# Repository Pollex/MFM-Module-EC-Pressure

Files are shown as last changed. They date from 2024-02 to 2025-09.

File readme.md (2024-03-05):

## TODOs

### Open Q's
- [ ] Calibration must happens when probe is switched. When and how to do this?
- [ ] Is it worth disabling the EZO circuit LED?
  - Perhaps sending the command takes more power than the LED being on

### Atlas Scientific EZO Circuit
- [ ] Send probe K value from EEPROM in perform_measurement
- [ ] Send calibration string from EEPROM in perform_measurement
- [ ] Send water temperature from EEPROM in perform_measurement

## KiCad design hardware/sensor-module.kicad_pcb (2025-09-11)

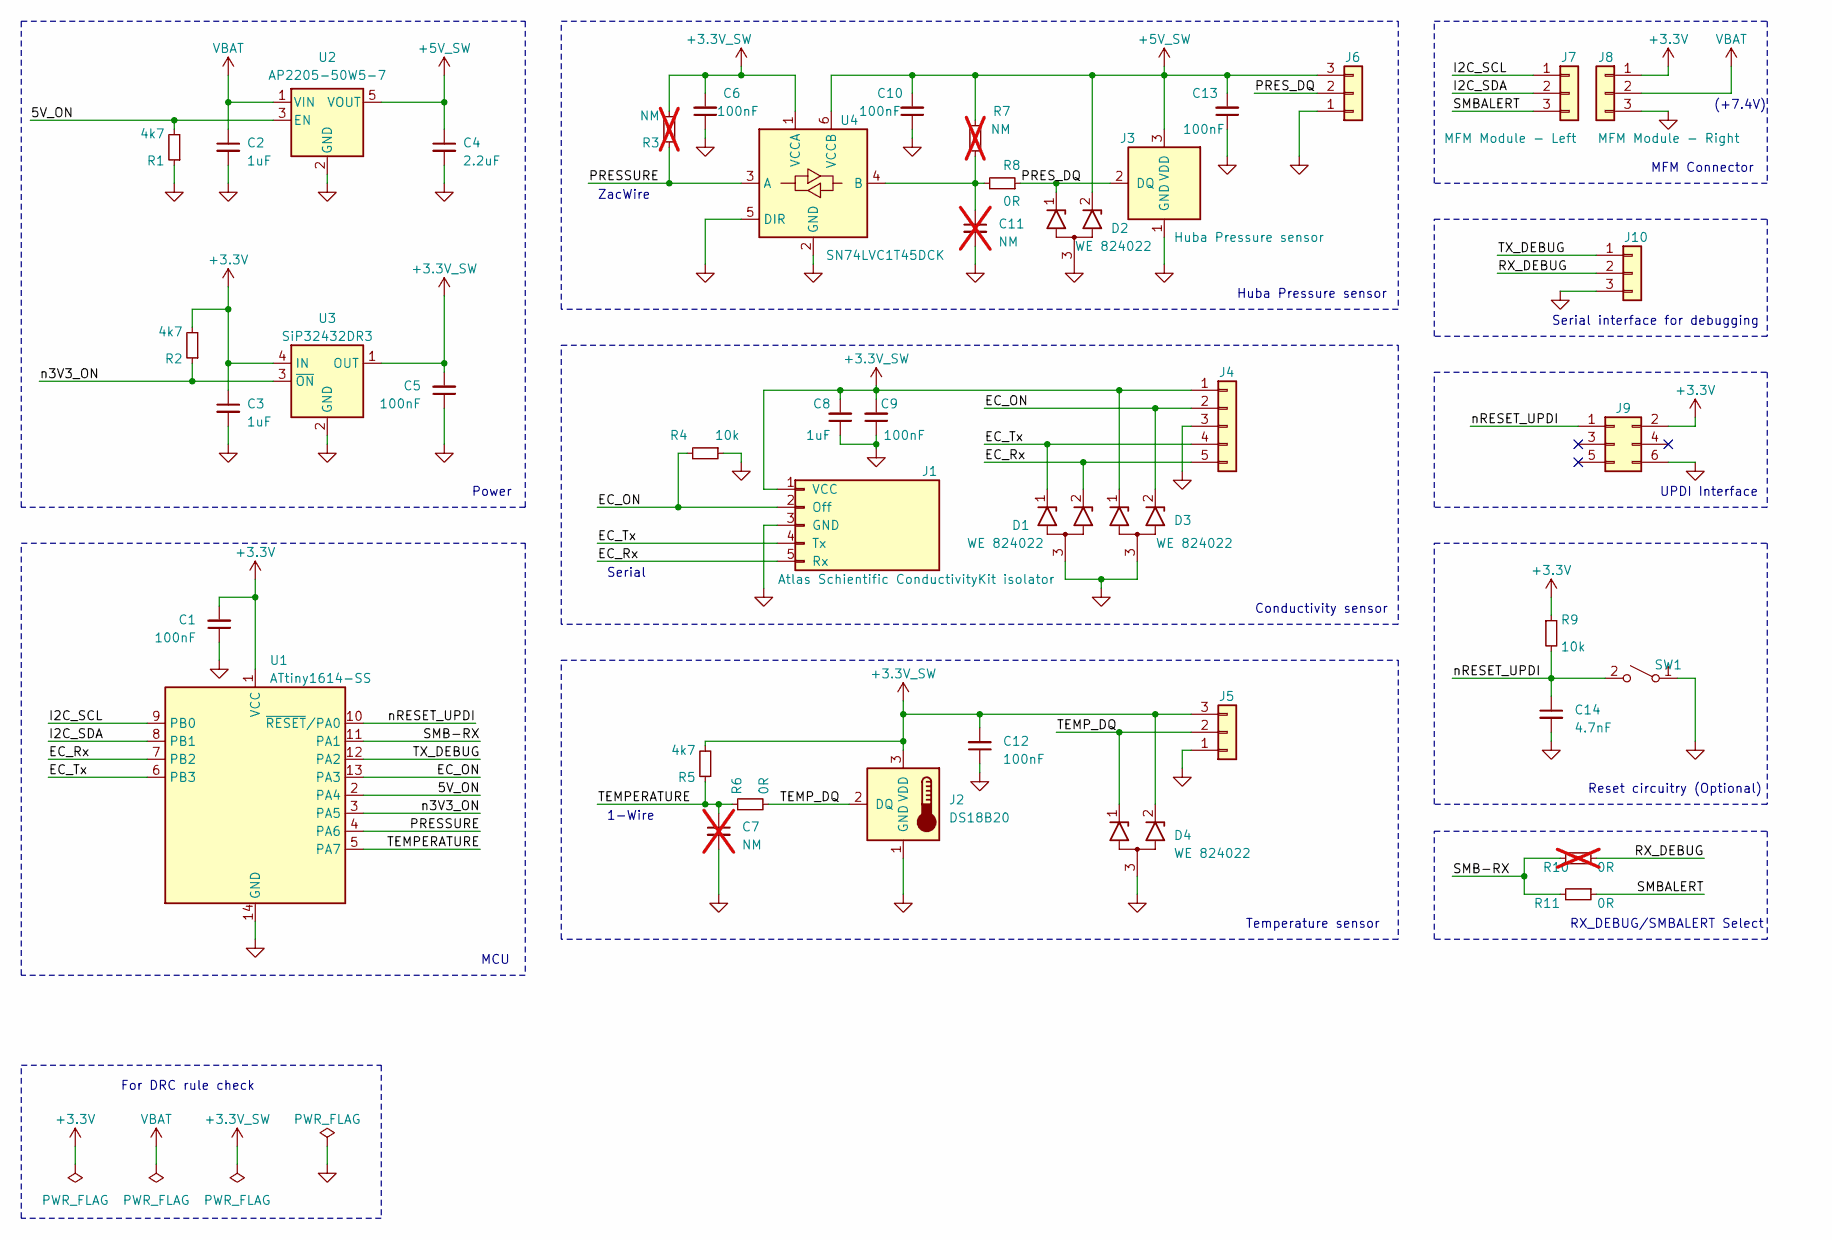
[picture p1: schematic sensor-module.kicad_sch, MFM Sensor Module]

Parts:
C1, C5, C6, C9, C10, C12, C13: 100nF; C_0603_1608Metric
C2, C3, C8: 1uF; C_0805_2012Metric
C4: 2.2uF; C_0805_2012Metric
C7, C11: NM; C_0603_1608Metric; not fitted
C14: 4.7nF; C_0603_1608Metric
D1, D2, D3, D4: WE 824022; SOT-23-3L
J1: Atlas Schientific ConductivityKit isolator; TerminalBlock_Phoenix_MPT-0,5-5-2.54_1x05_P2.54mm_Horizontal
J2: DS18B20; TerminalBlock_Phoenix_MPT-0,5-3-2.54_1x03_P2.54mm_Horizontal
J3: Huba Pressure sensor; TerminalBlock_Phoenix_MPT-0,5-3-2.54_1x03_P2.54mm_Horizontal
J4: Conductivity; PinHeader_1x05_P2.54mm_Vertical
J5: Temperature; PinHeader_1x03_P2.54mm_Vertical
J6: Huba Pressure; PinHeader_1x03_P2.54mm_Vertical
J7: MFM Module - Left; PinHeader_1x03_P2.54mm_Vertical
J8: MFM Module - Right; PinHeader_1x03_P2.54mm_Vertical
J9: UPDI Interface; PinHeader_2x03_P2.54mm_Vertical
J10: Debug UART; PinHeader_1x03_P2.54mm_Vertical
R1, R2, R5: 4k7; C_0603_1608Metric
R3, R7: NM; C_0603_1608Metric; not fitted
R4, R9: 10k; C_0603_1608Metric
R6, R8, R11: 0R; C_0603_1608Metric
R10: 0R; C_0603_1608Metric; not fitted
SW1: PTS636 SM43 SMTR LFS; SW_Tactile_SPST_NO_Straight_CK_PTS636Sx25SMTRLFS
U1: ATtiny1614-SS; SOIC-14_3.9x8.7mm_P1.27mm
U2: AP2205-50W5-7; SOT-23-5
U3: SiP32432DR3; SOT-363_SC-70-6
U4: SN74LVC1T45DCK; SOT-363_SC-70-6

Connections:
+3.3V: C1.2, C3.1, J8.1, J9.2, R2.2, R9.1, U1.1 (VCC), U3.4 (IN)
+3.3V_SW: C5.2, C6.2, C8.2, C9.2, C12.2, D3.1 (K1), D4.2 (K2), J1.1 (VCC), J2.3 (VDD), J4.1, J5.3, R3.2, R5.2, U3.1 (OUT), U4.1 (VCCA)
+5V_SW: C4.1, C10.2, C13.2, D2.2 (K2), J3.3 (VDD), J6.3, R7.2, U2.5 (VOUT), U4.6 (VCCB)
/5V_ON: R1.2, U1.2 (PA4), U2.3 (EN)
/EC_ON: D3.2 (K2), J1.2 (Off), J4.2, R4.2, U1.13 (PA3)
/EC_Rx: D1.2 (K2), J1.5 (Rx), J4.5, U1.7 (PB2)
/EC_Tx: D1.1 (K1), J1.4 (Tx), J4.4, U1.6 (PB3)
/I2C_SCL: J7.1, U1.9 (PB0)
/I2C_SDA: J7.2, U1.8 (PB1)
/PRESSURE: R3.1, U1.4 (PA6), U4.3 (A)
/PRES_DQ: D2.1 (K1), J3.2 (DQ), J6.2, R8.1
/RX_DEBUG: J10.2, R10.1
/SMB-RX: R10.2, R11.2, U1.11 (PA1)
/SMBALERT: J7.3, R11.1
/TEMPERATURE: C7.1, R5.1, R6.1, U1.5 (PA7)
/TEMP_DQ: D4.1 (K1), J2.2 (DQ), J5.2, R6.2
/TX_DEBUG: J10.1, U1.12 (PA2)
/n3V3_ON: R2.1, U1.3 (PA5), U3.3 (~ON)
/nRESET_UPDI: C14.1, J9.1, R9.2, SW1.2 (B), U1.10 (~RESET/PA0)
GND: C1.1, C2.2, C3.2, C4.2, C5.1, C6.1, C7.2, C8.1, C9.1, C10.1, C11.2, C12.1, C13.1, C14.2, D1.3 (A), D2.3 (A), D3.3 (A), D4.3 (A), J1.3 (GND), J2.1 (GND), J3.1 (GND), J4.3, J5.1, J6.1, J8.3, J9.6, J10.3, R1.1, R4.1, SW1.1 (A), U1.14 (GND), U2.2 (GND), U3.2 (GND), U3.5 (GND), U4.2 (GND), U4.5 (DIR)
unnamed: C11.1, R7.1, R8.2, U4.4 (B)
VBAT: C2.1, J8.2, U2.1 (VIN)

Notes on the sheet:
Serial
Conductivity sensor
1-Wire
Huba Pressure sensor
Serial interface for debugging
Temperature sensor
ZacWire
RX_DEBUG/SMBALERT Select
(+7.4V)
For DRC rule check
MCU
MFM Connector
Power
UPDI Interface
Reset circuitry (Optional)

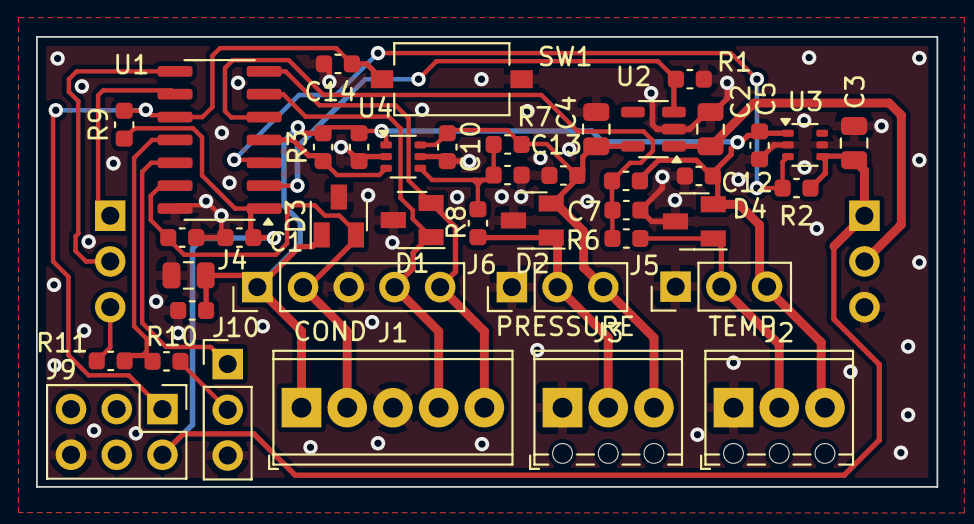
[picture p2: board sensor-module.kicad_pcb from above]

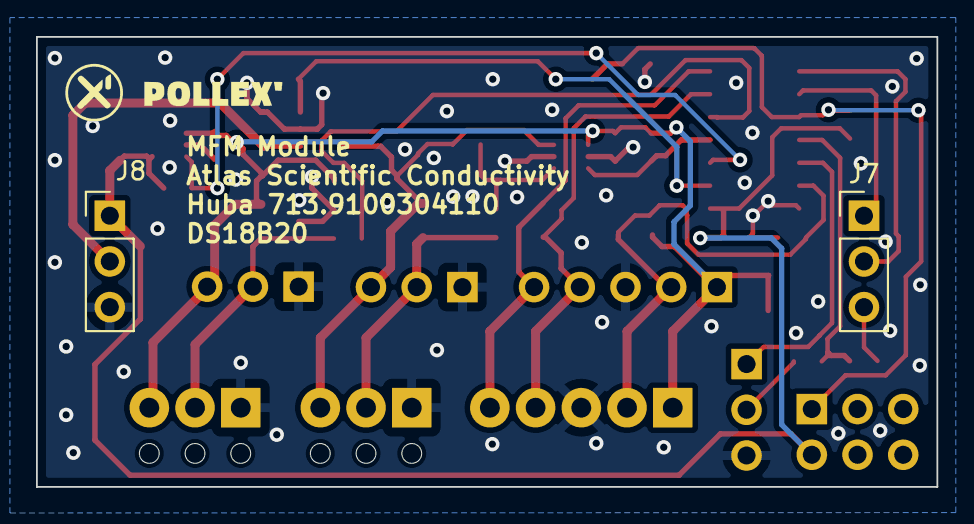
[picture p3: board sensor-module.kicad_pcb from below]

Board: 2 copper layers, 50.0 x 25.0 mm, 44 parts (2 on the bottom side), 22 nets.

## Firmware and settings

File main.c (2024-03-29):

// #include <stdio.h>
// #include <avr/iotn1614.h>
/// @mainpage MFM Sensor Module
/// @brief Main file for the MFM Sensor Module
/// @details This application will initialize the MFM Sensor board and perform
/// measurements from the following sensors:
/// - Huba713 sensor
/// - DS18B20 temperature sensor
/// - Atlas Scientific EZO EC sensor
/// Measurements are started by the I2C master by sending a command 0x10 to the
/// MFM Sensor Module (I2C address 0x36) The measurements will be stored in a
/// data packet and can be requested by the I2C master by sending a command 0x11
/// The data packet will be sent back to the I2C master and is defined as below,
/// - Number of bytes in the data packet (uint8_t)
/// - Huba713 pressure (uint16_t )
/// - Huba713 temperature (float in degrees Celsius)
/// - DS18B20 temperature (float in degrees Celsius)
/// - Atlas Scientific EZO EC conductivity (uint8_t[4]; string holding uS/cm)
/// The data will be in little-endian format
///
/// An example of the data packet:
/// > 0E C1 0B E0 7A A4 41 00 00 AD 41 30 2E 30 30
///
/// - Number of data bytes: 14
/// - Pressure: 3009
/// - Temperature: 20.5599975585
/// - ds18b20_temperature: 21.625
/// - conductivity: 0.00
/// When the MFM Sensor Module is not performing measurements, it will be in
/// sleep mode to save power

#include "board/mfm_sensor_module.h"

#include <avr/io.h>
#include <avr/wdt.h>

#include <avr/interrupt.h>
#include <avr/sleep.h>
#include <stdint.h>
#include <util/atomic.h>

#include "drivers/zacwire.h"
#include "mcu/twi.h"
#include "mcu/util.h"
#include "os/os.h"
#include "perif/atlas_ezo_ec.h"
#include "perif/ds18b20.h"
#include "perif/huba713.h"
#include <string.h>

// Power control
#define PWR_DISABLE 0x00
#define PWR_ENABLE 0x01

// forward declarations
static void pwr_5vEnable(uint8_t enable);
static void pwr_3v3Enable(uint8_t enable);
static void pwr_init(void);

void perform_measurements(void);

#define FLAG_CALIBRATED 0x01
#define FLAG_HUBA_ERR 0x02
#define HUBA_MEDIAN_COUNT 11

// Forward declaration of variables
/// @brief I2C Data packet
struct packet_t {
    uint16_t huba_pressure;
    float huba_temperature;
    float ds18b20_temperature;
    uint8_t atlas_conductivity[8];
    uint8_t flags;
} packet;

// "tasks" that will be performed on wakeup (interrupt)
volatile uint8_t doCalibration = 0;
volatile uint8_t doMeasurement = 0;

/// @brief DS18B20 struct to hold resolution, defined here so we can set it once
/// in main
ds18b20_t d;

/// @brief Initialize the power control
/// @details 5V and 3V3 will be disabled after initialization
void pwr_init(void) {
    ENABLE_5V_PORT.DIRSET = ENABLE_5V_PIN;   // 5V_on as output
    ENABLE_3V3_PORT.DIRSET = ENABLE_3V3_PIN; // 3V3_on as output

    pwr_3v3Enable(PWR_DISABLE);
    pwr_5vEnable(PWR_DISABLE);
}

/// @brief Enable/disable 5V
/// @param enable PWR_DISABLE (0x00) to disable, PWR_ENABLE (0x01) to enable
void pwr_5vEnable(uint8_t enable) {
    if (enable > 0) {
        ENABLE_5V_PORT.OUTSET = ENABLE_5V_PIN; // Switch 5V_on to on
    } else {
        ENABLE_5V_PORT.OUTCLR = ENABLE_5V_PIN; // Switch 5V_on to off
    }
}

/// @brief Enable/disable 3V3
/// @param enable PWR_DISABLE (0x00) to disable, PWR_ENABLE (0x01) to enable
void pwr_3v3Enable(uint8_t enable) {
    if (enable > 0) {
        ENABLE_3V3_PORT.OUTCLR = ENABLE_3V3_PIN; // Switch 3V3_on to on
    } else {
        ENABLE_3V3_PORT.OUTSET = ENABLE_3V3_PIN; // Switch 3V3_on to off
    }
}

/* Function to sort an array using insertion sort*/
void insertion_sort_u16(uint16_t arr[], int n) {
    int i, key, j;
    for (i = 1; i < n; i++) {
        key = arr[i];
        j = i - 1;

        /* Move elements of arr[0..i-1], that are
        greater than key, to one position ahead
        of their current position */
        while (j >= 1 && arr[j] > key) {
            arr[j + 1] = arr[j];
            j = j - 1;
        }
        arr[j + 1] = key;
    }
}

/* Function to sort an array using insertion sort*/
void insertion_sort_f(float arr[], int n) {
    int i, key, j;
    for (i = 1; i < n; i++) {
        key = arr[i];
        j = i - 1;

        /* Move elements of arr[0..i-1], that are
        greater than key, to one position ahead
        of their current position */
        while (j >= 1 && arr[j] > key) {
            arr[j + 1] = arr[j];
            j = j - 1;
        }
        arr[j + 1] = key;
    }
}

/// @brief Perform measurements from different sensors and store them in global
/// variables
/// @details This function is called from the twi_perform_task, which is called
/// from the I2C ISR it will enable 5V and 3V3, initialize sensors, perform the
/// measurements and disable 5V and 3V3
void perform_measurements() {
    // Conductivity data (string holding uS/cm)
    static uint8_t conductivity[8] = {0};
    static float ds18b20_temperature;
    static uint16_t huba_pressure = 0;
    static float huba_temperature = 0.0;

    uint16_t median_pressure[HUBA_MEDIAN_COUNT] = {0};
    float median_temperature[HUBA_MEDIAN_COUNT] = {0};

    // Enable 5V and 3V3
    pwr_5vEnable(PWR_ENABLE);
    pwr_3v3Enable(PWR_ENABLE);
    delay_ms(10);

    // Measure huba sensor using median filter
    int errs = 0;
    int index = 0;
    for (uint8_t tries = 0; tries < HUBA_MEDIAN_COUNT; tries++) {
        // read value from Huba sensor (zacwire)
        int err = huba713_read(&huba_pressure, &huba_temperature);
        if (err == 0) {
            median_pressure[index] = huba_pressure;
            median_temperature[index++] = huba_temperature;
        } else {
            errs++;
        }
    }

    // The HUBA sensor is the only sensor in need of 5V, so disable it after
    // reading
    pwr_5vEnable(PWR_DISABLE);

    // Prepare HUBA Sensor values
    if (errs > 0) {
        packet.flags |= FLAG_HUBA_ERR;
    }
    // Make sure there is atleast one valid measurements to perform median
    if (index > 0) {
        insertion_sort_u16(median_pressure, index);
        insertion_sort_f(median_temperature, index);
        huba_pressure = median_pressure[index / 2];
        huba_temperature = median_temperature[index / 2];
    } else {
        // Otherwise error
        huba_pressure = 0;
        huba_temperature = 200.0f;
    }
    delay_us(1000);

    // read value from DS18B20 sensor (one-wire)
    ds18b20_read(&d, 0);
    ds18b20_temperature = ds18b20_read(&d, 0);

    // Turn the Atlas Scientific EZO EC sensor on by setting the enable pin
    atlas_ezo_ec_enable();

    // We only want to read the value once, so disable continuous reading
    atlas_ezo_ec_disableContinuousReading();

    // Set temperature compensation
    if (ds18b20_temperature > -50 && ds18b20_temperature < 50) {
        atlas_ezo_ec_setTemperature((uint8_t)ds18b20_temperature);
    } else {
        atlas_ezo_ec_setTemperature(10);
    }

    if (doCalibration) {
        atlas_ezo_ec_calibrate();
        packet.flags |= FLAG_CALIBRATED;
        doCalibration = 0;
    }

    // read value from Atlas Scientific EZO EC sensor (UART)
    atlas_ezo_ec_requestValue(conductivity);

    // Small delay before turning off the sensor
    delay_us(200);
    // Turn the Atlas Scientific EZO EC sensor off by clearing the enable pin
    atlas_ezo_ec_disable();

    // Small delay to give the CPU time to read the last data from the UART
    delay_us(500);

    // All done, so disable 3V3
    pwr_3v3Enable(PWR_DISABLE);

    // Store the data in data struct
    packet.huba_pressure = huba_pressure;
    packet.huba_temperature = huba_temperature;
    packet.ds18b20_temperature = ds18b20_temperature;
    for (int ii = 0; ii < 8; ii++) {
        packet.atlas_conductivity[ii] = conductivity[ii];
    }
}

/// @brief Handler for cmd 0x80 from I2C master
/// @details Triggers a calibration
/// @param buf Pointer to the buffer to store the data in
/// @param len Length of the buffer
void twi_cmd_80_handler(uint8_t *buf, uint8_t len) { doCalibration = 1; }

/// @brief Handler for cmd 0x11 from I2C master
/// @details Copies the sensor data from the data packet to the bus; kept short
/// as possible!
/// @param buf Pointer to the buffer to store the data in
/// @param len Length of the buffer
void twi_cmd_11_handler(uint8_t *buf, uint8_t len) {
    buf[0] = sizeof(struct packet_t);
    memcpy(&buf[1], &packet, buf[0]);
    memset(&packet, 0, sizeof(struct packet_t));
}

/// @brief Handler for cmd 0x10 from I2C master
/// @details Creates a task to start measurements; kept short as possible!
/// @param buf Pointer to the buffer to store the data in, not used
/// @param len Length of the buffer, not used
void twi_cmd_10_handler(uint8_t *buf, uint8_t len) { doMeasurement = 0x01; }

/// @brief Accapted TWI (I2C) commands
twi_cmd_t twi_cmds[] = {
    {0x10, &twi_cmd_10_handler},
    {0x11, &twi_cmd_11_handler},
    {0x80, &twi_cmd_80_handler},
};

/// @brief Waits for the watchdog to sync
/// @details
void wdt_sync(void) {
    // Wait for data to synchronize between clock and wdt domain
    while ((WDT.STATUS & WDT_SYNCBUSY_bm) == WDT_SYNCBUSY_bm)
        ;
}

/// @brief Function called before entering sleep
/// @details Disables BOD to save power; Disable the watchdog timer
void os_presleep() {
    wdt_disable();
    wdt_sync();
}

/// @brief Function called after waking up from sleep
void os_postsleep(void) {
    wdt_enable(WDT_PERIOD_8KCLK_gc);
    wdt_sync();
}

/// @brief main function
int main() {
    doMeasurement = 0;

    os_init();

    // Initialize the delay system
    delay_init();
    delay_ms(500);

    // Initialize the power control
    pwr_init();

    // Set resolution of DS18B20 temperature sensor
    d.resolution = DS18B20_RES_12;

    // Initialize EZO EC
    atlas_ezo_ec_init();

    // Initialize the HUBA sensor
    huba713_init();

    // Enable interrupts
    sei();

    // Initialize the TWI Interface (set address to 0x36)
    twi_init(0x36, 1);

    // Set BOD mode for sleep mode (Disabled to save power)
    _PROTECTED_WRITE(BOD_CTRLA, BOD_CTRLA & ~(BOD_SLEEP_gm));

    // Set the watchdog timer
    wdt_enable(WDT_PERIOD_8KCLK_gc);
    wdt_sync();

    // Main loop
    while (1) {
        // Check if we need to perform measurements
        if (doMeasurement == 0x01) {
            doMeasurement = 0x00;
            perform_measurements();
        }

        // Kick the watchdog
        wdt_reset();

        // Sleep the system, note: watchdog will be disabled during sleep
        os_sleep();
    }
}

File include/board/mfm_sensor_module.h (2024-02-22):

//
// Created by Eric van Rijswick on 31/01/2024.
//

/// @file mfm_sensor_module.h
/// @brief Holds parameters for MFM Sensor Module board

#ifndef MFM_SENSOR_MODULE_MFM_SENSOR_MODULE_H
#define MFM_SENSOR_MODULE_MFM_SENSOR_MODULE_H

#include <avr/io.h>

#define USART_PORT PORTB
#define USART_RX_PIN PIN3_bm
#define USART_TX_PIN PIN2_bm

#define USART_ALTERNATE_PORT PORTA
#define USART_RX_ALTERNATE_PIN PIN2_bm
#define USART_TX_ALTERNATE_PIN PIN1_bm

#define USART_DEFAULT_PINS 0x00
#define USART_ALTERNATE_PINS 0x01

#define ENABLE_CONDUCTIVITY_PORT PORTA
#define ENABLE_CONDUCTIVITY_PIN PIN3_bm

#define ENABLE_5V_PORT PORTA
#define ENABLE_5V_PIN PIN4_bm
#define ENABLE_3V3_PORT PORTA
#define ENABLE_3V3_PIN PIN5_bm

#define ZACWIRE_PORT PORTA
#define ZACWIRE_PIN PIN6_bm
#define ZACWIRE_PINp PIN6_bp

#define TEST_PORT PORTA
#define TEST_PIN PIN2_bm

#endif //MFM_SENSOR_MODULE_MFM_SENSOR_MODULE_H

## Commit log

2024-02-21 Increase value string for ec sensor
2024-02-22 Test INT/TMR driven Zacwire (fail)
    [main.c, mfm_sensor_module.h]
2024-02-23 Implement ZACWire with duty cycle calibration
2024-03-05 Implement calibration and temp compensation
2024-03-05 fix(ec): calibrate during measurement, fix invalid buf
    [atlas_ezo_ec.c, main.c]
2024-03-07 feat(huba): add median filter
2024-03-29 Fix: Zacwire parity, Huba median calculation
    [atlas_ezo_ec.c, main.c]
2024-03-29 Chore: Update Kicad file version
    [sensor-module.kicad_pcb]
2024-04-10 Hardware: add screw terminals
    [sensor-module.kicad_pcb, sensor-module.kicad_sch]
2025-09-11 kicad version upgrade, add ignores, add missing import
    [sensor-module.kicad_pcb]
